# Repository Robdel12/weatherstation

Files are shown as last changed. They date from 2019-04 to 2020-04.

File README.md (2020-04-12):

# Weather-station



This is my project weather station built with a Particle Photon and Sparkfun
weather shield (and meters). That `POST`s data a Node / Express / MongoDB
server. That server also will be the API which the React PWA will query for
data.

## Getting started

First thing you need to do is flash your Photon with the firmware that's inside
of `firmware/weatherstation.ino`. Be sure to update [this
line](https://github.com/Robdel12/weatherstation/tree/master/firmware/weatherstation.ino#L177)
with your own server's hostname.

After the Photon is flashed, you should deploy this server to where ever you
want or expose your local server via ngrok.

Now go to `[YOUR_SERVER_URL]/weather` with the Photon connected to power to see
if data is being collected properly.

### TODO

Document how to setup server, run client, etc. Very much WIP right
now. Check the `package.json` scripts for hints

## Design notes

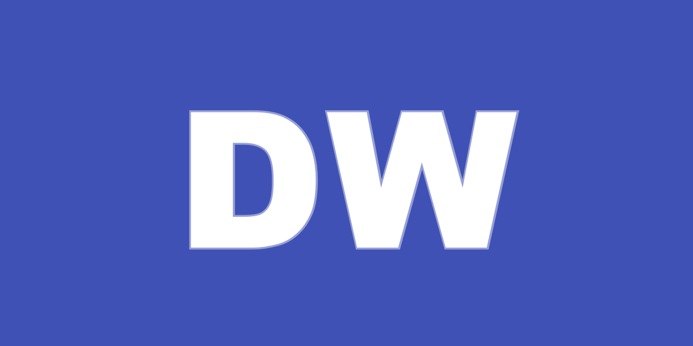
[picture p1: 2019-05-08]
designs/graphic/github-project.png

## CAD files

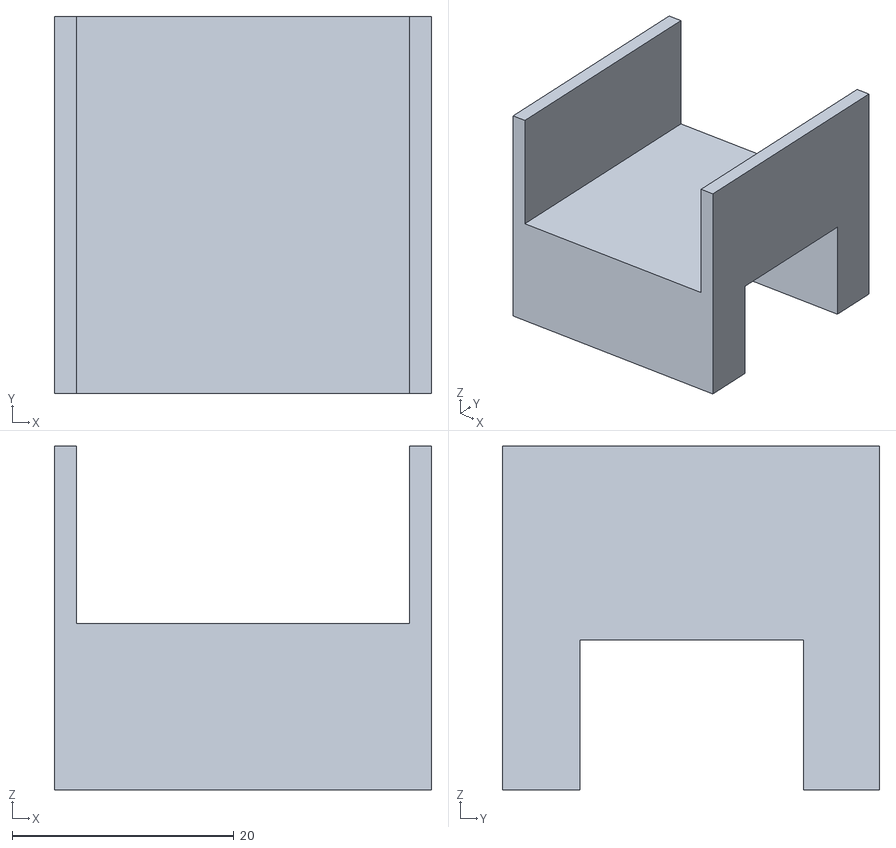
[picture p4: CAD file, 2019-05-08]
designs/3d/Battery box mount v4.stl
34.0 x 34.0 x 31.0

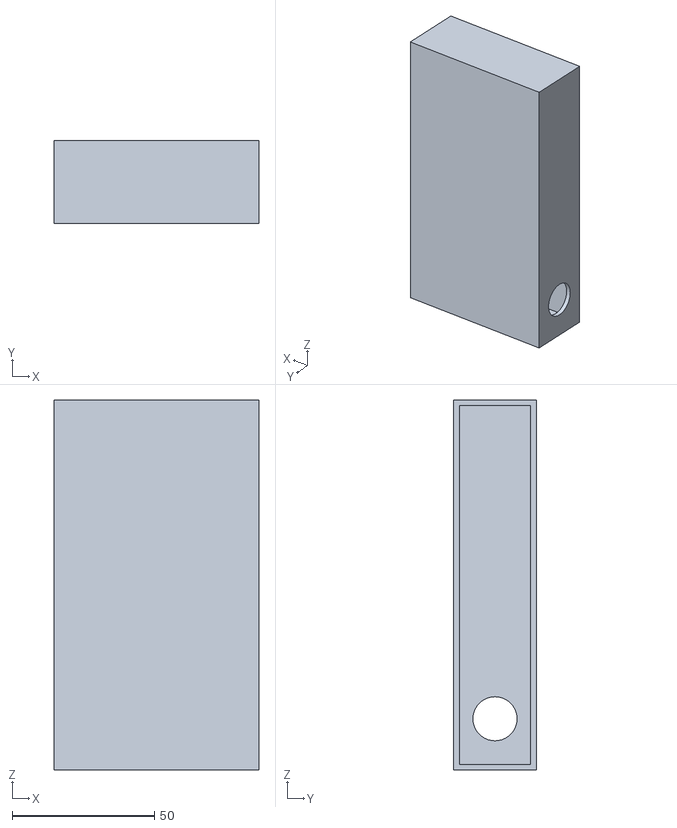
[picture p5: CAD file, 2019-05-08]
designs/3d/battery-box-2 v2.stl
72.0 x 29.0 x 130.0

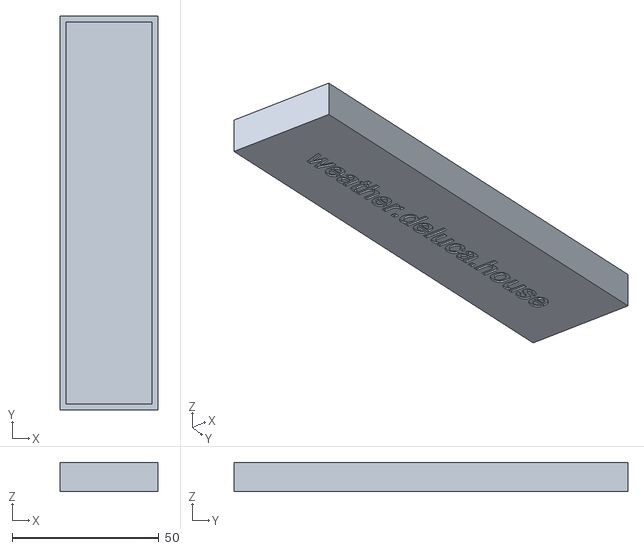
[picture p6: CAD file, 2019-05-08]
designs/3d/Battery box cover v2.stl
33.2 x 134.2 x 10.0

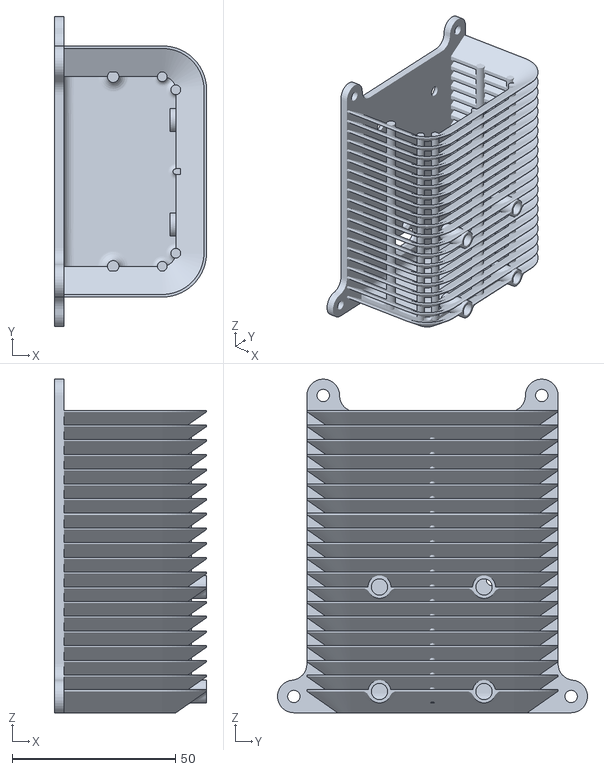
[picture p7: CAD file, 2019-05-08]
designs/3d/stevenson-screen.stl
46.6 x 94.8 x 102.1

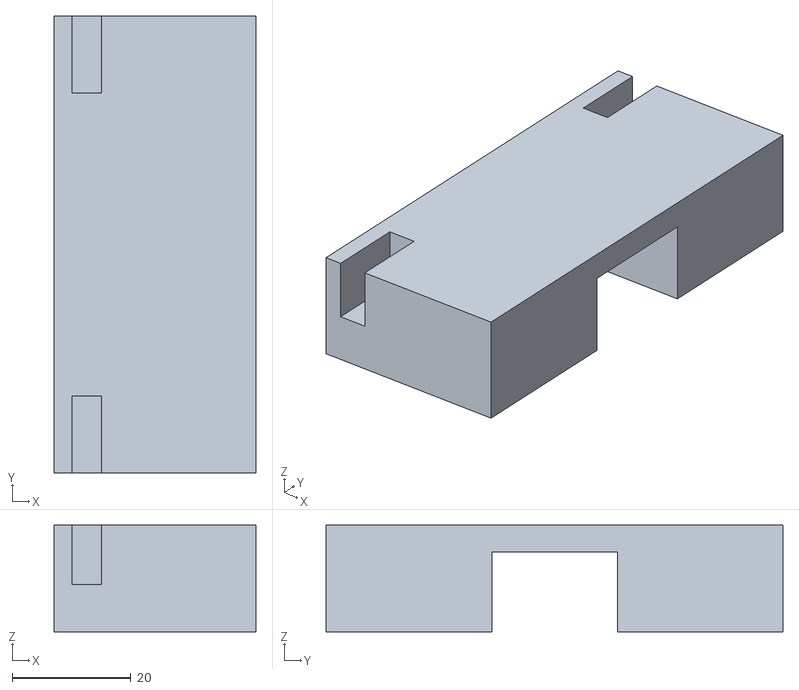
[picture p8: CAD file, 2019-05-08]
designs/3d/Stevenson screen mount v3.stl
34.0 x 77.0 x 18.0

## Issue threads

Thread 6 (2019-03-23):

Calibrate wind direction

Robdel12, 2019-03-23:
Currently the wind direction is not accurate and is not calibrated.

@wwilsman where’s that gist at? 🤣

wwilsman, 2019-03-23:
https://gist.github.com/wwilsman/8cb9dc369f68053001002e1920d9bc49

The APDS file is for the light sensor. If you haven't hooked that up yet you can delete the relevant light sensor code along with that file

Robdel12, 2019-05-18:
Turns out it actually was. I do need to implement the better wind direction firmware you have though. Going to open a separate issues

Closed 2019-05-18.

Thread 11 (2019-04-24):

Stevenson screen is too small

Robdel12, 2019-04-24:
The current printed Stevenson screen is too small and traps heat. This causes the temperature reading to be way high when in direct sunlight.

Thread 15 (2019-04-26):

Calculate dew point

Robdel12, 2019-04-26:
The data is present, just need to make the calculation.

https://en.m.wikipedia.org/wiki/Dew_point#Simple_approximation

wwilsman, 2020-04-12:
Wonder if this and #16 could be done with a MongoDB query similar to average wind direction in V2? 🤔

Robdel12, 2020-04-12:
I was thinking about this -- we're going to need to solve the humidity accuracy issue first. I need to fix my printer so I can print a bigger base for the larger stevenson screen.

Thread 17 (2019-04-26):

Adjust raw pressure value to elevation

Robdel12, 2019-04-26:
The pressure displayed in the app currently is raw and not adjusted for altitude. Once that’s done it’ll be an accurate reading.

https://www.weather.gov/epz/wxcalc_pressurealtitude

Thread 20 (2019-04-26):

Routing is not accessible

Robdel12, 2019-04-26:
Currently the routing in the React app does not manage focus, so screen readers and other AT won’t be able to navigate.

Robdel12, 2019-04-27:
Closed with #27

Closed 2019-04-27.

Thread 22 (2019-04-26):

Humidity can exceed 100%

Robdel12, 2019-04-26:
That seems wrong. Maybe cap that display in the UI.

Also, is that valid?

wwilsman, 2020-03-18:
Humidity can indeed exceed 100% 😅 It's called supersaturation.

Should we close this or do you think it was way too far above 100% to be accurate?

Robdel12, 2020-03-18:
I think we should cap it. Also does funky things where it "ticks over" to single digit percentages again. It's weird 🤔

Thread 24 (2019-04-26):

Provide a way to navigate historical data

Robdel12, 2019-04-26:
Maybe have a data explorer route that allows you to pick a date range and graph the different data points. It’d be neat to do time comparisons too.

wwilsman, 2020-04-12:
This will be so much better with #226 ❤️

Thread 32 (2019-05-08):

Organize express server better

Robdel12, 2019-05-08:
It's probably about time to break up the big 'ol `index.js` file into various smaller files that are organized and make sense.

wwilsman, 2020-04-12:
Do you think this issue still applies to queries in V2? Or is this a non-issue now that V1 probably won't be maintained with the advent of #226?

Robdel12, 2020-04-12:
I think it’s a non-issue 👍

Closed 2020-04-12.

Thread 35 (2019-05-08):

Focus is not set within the nav menu when opened

Robdel12, 2019-05-08:
This issue prevents AT users from being able to navigate to various different routes.

Robdel12, 2020-08-24:
No longer relevant with material UI being ripped out

Closed 2020-08-24.

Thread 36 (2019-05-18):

Improve how wind direction is captured

Robdel12, 2019-05-18:
Now that the wind direction is calibrated and accurate, it’s time to stop capturing “none” as a wind direction. Wil did a great job debugging and writing the firmware to  accurately capture the sensor data: https://gist.github.com/wwilsman/8cb9dc369f68053001002e1920d9bc49

wwilsman, 2020-04-12:
#198 captures wind direction better and #226 does on-the-fly migration of old data 🎉

Closed 2020-04-12.

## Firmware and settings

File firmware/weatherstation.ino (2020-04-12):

#include "SparkFun_Photon_Weather_Shield_Library.h"
#include "Sparkfun_APDS9301_Library.h"

// interrupt pins
const int WDIR_PIN = A0;
const int WSPEED_PIN = D3;
const int RAIN_PIN = D2;
// i2c address
const uint8_t LUX_ADDR = 0x39;

// local data
float humidity = 0;
float temp = 0;
float pascals = 0;
float windD = 0;
float windS = 0;
float rain = 0;
float lux = 0;

// tracks update interval
long lastUpdate = 0;

// weather sheild sensor
Weather weather;
// ambient light sensor
APDS9301 light;

// updates local weather data
void updateWeatherData() {
  // relative humidity
  humidity = weather.getRH();
  // tempurature (getRH makes this faster than readTemp)
  temp = weather.getTempF();
  // barometer
  pascals = weather.readPressure();
  // average temp between both sensors
  temp = (temp + weather.readBaroTempF()) / 2;
  // wind
  windS = getWindSpeed();
  windD = getWindDirection();
  // rain
  rain = getRainInches();
  // light
  lux = light.readLuxLevel();
}

// rain functions
volatile long lastRainIRQ = 0;
volatile byte rainClicks = 0;

void rainIRQ() {
  // ignore switch-bounce glitches
  if (millis() - lastRainIRQ > 10) {
    lastRainIRQ = millis();
    rainClicks++;
  }
}

float getRainInches() {
  // calculate inches of rain from clicks
  float rainIn = rainClicks * 0.011;
  // reset rain clicks
  rainClicks = 0;
  return rainIn;
}

// wind functions
volatile long lastWindIRQ = 0;
volatile byte windClicks = 0;

void windIRQ() {
  // ignore switch-bounce glitches
  if (millis() - lastWindIRQ > 10) {
    lastWindIRQ = millis();
    windClicks++;
  }
}

long lastWindCheck = 0;

float getWindSpeed() {
  // calculate clicks per second
  float deltaTime = (millis() - lastWindCheck) / 1000.0;
  float windSpeed = (float) windClicks / deltaTime;
  // reset wind clicks
  lastWindCheck = millis();
  windClicks = 0;
  // multiply clicks per second by mph per click
  windSpeed *= 1.492;
  return windSpeed;
}

float getWindDirection() {
  // get the current reading from the sensor
  int adc = analogRead(WDIR);

  // adc -> dir

  // manual testing results:
  // ~1485 -> 112.5
  // ~1556 -> 67.5
  // ~1592 -> 90
  // ~1716 -> 157.5
  // ~1928 -> 135
  // ~2135 -> 202.5
  // ~2276 -> 180
  // ~2646 -> 22.5
  // ~2808 -> 45
  // ~3170 -> 247.5
  // ~3248 -> 225
  // ~3421 -> 337.5
  // ~3610 -> 0
  // ~3702 -> 292.5
  // ~3828 -> 315
  // ~3944 -> 270

  // rounded values account for fluctuation
  if (adc < 1500) return 112.5;
  if (adc < 1570) return 67.5;
  if (adc < 1600) return 90;
  if (adc < 1800) return 157.5;
  if (adc < 2000) return 135;
  if (adc < 2200) return 202.5;
  if (adc < 2400) return 180;
  if (adc < 2700) return 22.5;
  if (adc < 3000) return 45;
  if (adc < 3200) return 247.5;
  if (adc < 3300) return 225;
  if (adc < 3500) return 337.5;
  if (adc < 3650) return 0;
  if (adc < 3750) return 292.5;
  if (adc < 3850) return 315;
  if (adc < 4000) return 270;

  return -1; // error, disconnected?
}

//----------------------------------------------

void setup() {
  // open serial over USB at 9600 baud
  Serial.begin(9600);
  // initialize the weather sensors
  weather.begin();
  weather.setModeBarometer();
  weather.setOversampleRate(7);
  weather.enableEventFlags();
  // set windspeed and rain pin modes
  pinMode(WSPEED_PIN, INPUT_PULLUP);
  pinMode(RAIN_PIN, INPUT_PULLUP);
  // attach external interrupt pins to IRQ functions
  attachInterrupt(WSPEED_PIN, windIRQ, FALLING);
  attachInterrupt(RAIN_PIN, rainIRQ, FALLING);
  // turn on interrupts
  interrupts();
  // initialize i2c bus for light sensor
  Wire.begin();
  // light sensor setup
  light.begin(LUX_ADDR);
}

void loop() {
  // every 2 seconds
  if (millis() - lastUpdate >= 2000) {
    lastUpdate = millis();
    // update local data from all sensors
    updateWeatherData();
    // and publish local data
    publishWeatherData();
  }
}

//----------------------------------------------

// publish to server
TCPClient client;
const char* domain = "weather.deluca.house";
const char* path = "/v2/collect";
const int port = 443;

void publishWeatherData() {
  String data = getWeatherData();

  if (client.connect(domain, port)) {
    client.printlnf("POST %s HTTP/1.1", path);
    client.printlnf("Host: %s", address);
    client.printlnf("Content-Length: %d", data.length());
    client.println("Content-Type: application/json");
    client.println();
    client.println(data);
    client.flush();
  } else {
    Serial.printlnf("CONNECTION FAILED: %s:%d", address, port);
  }

  // always publish to serial
  Serial.println(data);
}

// returns weather data as a JSON string
String getWeatherData() {
  return (
    "{ \"temperature\": " +
    String(temp, 3) +
    ", \"humidity\": " +
    String(humidity, 3) +
    ", \"pressure\": " +
    String(pascals / 100, 3) +
    ", \"windDirection\": " +
    String(windD, 1) +
    ", \"windSpeed\": " +
    String(windS, 3) +
    ", \"rain\": " +
    String(rain, 3) +
    ", \"lux\": " +
    String(lux, 3) +
    " }"
  );
}

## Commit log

2019-01-02 Update API to parse shortend sensor data keys
2019-01-05 Add a couple more points to the averages
2019-01-05 Add altitude, test pressure reading (is it really hPa?)
2019-03-23 Redesign app to use material UI (#2)
2019-05-08 Add 3d models (#34)
    This adds the stevenson screen, the screen mount, battery box, and battery cover
    3d models
    [Battery box cover v2.stl, Battery box mount v4.stl, Stevenson screen mount v3.stl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]
2019-08-19 Bump @material-ui/core from 3.9.2 to 3.9.3 (#61)
2019-12-02 Bump @material-ui/core from 3.9.3 to 3.9.4 (#134)
    Bumps [@material-ui/core](https://github.com/mui-org/material-ui/tree/HEAD/packages/material-ui) from 3.9.3 to 3.9.4.
    - [Release notes](https://github.com/mui-org/material-ui/releases)
    - [Changelog](https://github.com/mui-org/material-ui/blob/master/CHANGELOG.md)
    - [Commits](https://github.com/mui-org/material-ui/commits/v3.9.4/packages/material-ui)
2020-03-18 🏗 Use workspaces (#199)
    Keep app and server dependencies separate
2020-03-18 🚨 Use eslint (#200)
2020-03-20 🎨 Versionize server routes (#201)
    All v1 route definitions were moved to `server/v1/routes.js` and general
    application setup was moved to `server/index.js`
2020-03-21 🐛 Fix v1 collect route (#202)
    ## Purpose
    The routes were versionized with #201 but the collect route was never updated
2020-03-23 ✨ Add websocket server (#203)
    * ✨ Add websocket server
    The server is versioned as well so respective server versions can send different
    data. When a websocket connects to the v1 route it will recieve a message
    anytime the v1/collect endpoint updates the database.
    * 🐛 Properly handle websocket server versioning
    When new websocket server versions are created, they all cannot share the same http
    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
2020-03-23 🐛 Fix websocket upgrade url handling (#205)
2020-03-23 Bump @material-ui/core from 3.9.4 to 4.9.7 (#212)
2020-03-23 Bump @material-ui/icons from 3.0.2 to 4.9.1 (#214)
2020-03-25 Add `.env` support (#204)
    * Add `.env` support
    I got tired of setting the prod mongo db env var. So now I'll write it to a file
    and never need to again
    * Update `.gitignore`
2020-03-30 Bump @material-ui/core from 4.9.7 to 4.9.8 (#223)
2020-04-11 Bump @material-ui/core from 4.9.8 to 4.9.9 (#224)
2020-04-12 ✨ V2 API (#226)
    * ✨ Add v2 graphql route
    * ✨ Add graphql weather schema
    * ➕ Hoist mocha devDependency
    * ✨ Add timeframe parser for easy queries
    * ✨ Add graphql query resolvers
    * ✨ Add v2/collect endpoint
    * 🐛 Convert v1 values to v2 values
    This was previously only a map, but v2 averages barometerTemp and has an entire
    different type for wind direction
    * ✨ Add week grouping and parsing
    * 🐛 Properly calculate wind direction average
    * ♻️ Move V1 server migration query to own module
    Hope is to eventually remove this on-the-fly migration once the database has
    actually been migrated
    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
2020-04-12 ♻️ Update and refactor firmware (#198)
    * ♻️ Update and refactor firmware
    * 📝 Update README to remove webhook setup
    * 👽 Use proper V2 API properties
    * ✨ Add light sensor firmware support
2020-04-13 Bump @material-ui/core from 4.9.9 to 4.9.10 (#232)
2020-04-20 Bump @material-ui/core from 4.9.10 to 4.9.11 (#238)
2020-04-27 Bump @material-ui/core from 4.9.11 to 4.9.12 (#243)
2020-05-04 Bump @material-ui/core from 4.9.12 to 4.9.13 (#252)
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2020-05-19 ✨ Websocket Live route (#227)
    * WIP: no more polling
    * useHooks for live component
    * tests: Update to handle websocks
    * Update the UI to give each data point a card
    Idk, seems okay
    * Update tests for new UI, fix lint
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2020-07-06 build(deps-dev): bump @material-ui/core from 4.10.2 to 4.11.0 (#311)
    Bumps [@material-ui/core](https://github.com/mui-org/material-ui/tree/HEAD/packages/material-ui) from 4.10.2 to 4.11.0.
    - [Changelog](https://github.com/mui-org/material-ui/blob/v4.11.0/CHANGELOG.md)
    - [Commits](https://github.com/mui-org/material-ui/commits/v4.11.0/packages/material-ui)
    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
2020-08-24 Remove material ui for tailwind (#352)
    * Remove Material UI
    * Setup Tailwind
    * Update tests
2020-11-07 ✨ New home route (#425)
    * Graphs?
    * Styles update
    * Fix deps
    * Skip tests (for now)
    We're going to be moving to the new version of Interactor, so these tests will
    need to be rewritten that way with GraphQL mocking in mind.
    * fix lint
2021-01-20 build(deps): [security] bump socket.io from 2.3.0 to 2.4.1 (#495)
2021-05-29 ⬆️ hosted-git-info from 2.8.8 to 2.8.9 (#618)
    Bumps [hosted-git-info](https://github.com/npm/hosted-git-info) from 2.8.8 to 2.8.9.
    - [Release notes](https://github.com/npm/hosted-git-info/releases)
    - [Changelog](https://github.com/npm/hosted-git-info/blob/v2.8.9/CHANGELOG.md)
    - [Commits](https://github.com/npm/hosted-git-info/compare/v2.8.8...v2.8.9)
2021-05-29 ⬆️ url-parse from 1.4.7 to 1.5.1 (#619)
    Bumps [url-parse](https://github.com/unshiftio/url-parse) from 1.4.7 to 1.5.1.
    - [Release notes](https://github.com/unshiftio/url-parse/releases)
    - [Commits](https://github.com/unshiftio/url-parse/compare/1.4.7...1.5.1)
2021-05-29 ⬆️ ua-parser-js from 0.7.23 to 0.7.28 (#620)
    Bumps [ua-parser-js](https://github.com/faisalman/ua-parser-js) from 0.7.23 to 0.7.28.
    - [Release notes](https://github.com/faisalman/ua-parser-js/releases)
    - [Commits](https://github.com/faisalman/ua-parser-js/compare/0.7.23...0.7.28)
2021-05-29 Upgrade to GitHub-native Dependabot (#596)
    * Upgrade to GitHub-native Dependabot
    * ♻️ Update config
    * ♻️ Update config
2021-05-29 ⬆️ Fix dependencies
2021-10-09 🚑️ Downgrade mongoDB dependency to avoid breaking changes
2021-10-11 :arrow_up: Bump mock-socket from 9.0.3 to 9.0.5 (#726)
    Bumps [mock-socket](https://github.com/thoov/mock-socket) from 9.0.3 to 9.0.5.
    - [Release notes](https://github.com/thoov/mock-socket/releases)
    - [Changelog](https://github.com/thoov/mock-socket/blob/master/CHANGELOG.md)
    - [Commits](https://github.com/thoov/mock-socket/commits)
    ---
    updated-dependencies:
    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
2021-10-18 :arrow_up: Bump mock-socket from 9.0.5 to 9.0.6 (#736)
    Bumps [mock-socket](https://github.com/thoov/mock-socket) from 9.0.5 to 9.0.6.
    - dependency-name: mock-socket
    dependency-type: direct:development
    update-type: version-update:semver-patch
    ...
    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
2021-11-01 :arrow_up: Bump mock-socket from 9.0.6 to 9.0.7 (#754)
    Bumps [mock-socket](https://github.com/thoov/mock-socket) from 9.0.6 to 9.0.7.
    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
2021-11-05 ♻️🏗 Remove Webpack & Karma, replace with Parcel & Cypress (#757)
    * ♻🏗️ Refactor to use Parcel 2 over Webpack
    'cause I wanted to use it and also too lazy to upgrade to the next major version
    of webpack
    * ♻️🏗 Remove Karma tests, use Cypress
    This is because Parcel isn't really going to work well with Karma. As much as I
    love Karma, I don't want to sink my time into making it work well with
    Parcel. The wins from using Cypress is these are E2E tests hitting the local
    server (I've been trolled by dep updates in the past because of the mocked API)
    and it makes us make interactor.js work with Cypress.
    * 🏗 Add GitHub actions
2021-11-06 🐛 Fix error handling in home
    I was trying to render an error object rather than the message from the
    error. This caused react to error since you can't try to render an object like
    that (lol)
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
